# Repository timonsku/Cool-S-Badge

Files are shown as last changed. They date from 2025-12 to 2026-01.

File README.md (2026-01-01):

# Cool-S-Badge

Targets nRF Connect 3.1.1

For Assembly check the docs folder.
TRIPPLE CHECK THE PRO MICRO ORIENTATION before soldering in place

Always update the firmware with the latest version committed to the root of the repo.

OTA Firmware Update
----------------
Download Nordic Device Manager and select the zip file in the DFU/Image tab.
Takes about 30sec after upload before it comes back online.
https://www.nordicsemi.com/Products/Development-tools/nRF-Connect-Device-Manager

Step by step instructions can be found in [OTA.md](docs/OTA/OTA.md)

How to set colors
----------------
Use the "iPixel Color" app in "DIY Drawing" mode to apply LED colors.
Animation support coming soon, bit buggy right now.
Brightness adjustment in Settings menu works but does not persists right now.
Colors persist through reboots if you pressed OK in the editor.

Click the big plus sign to find devices. They are called "LED_XXXXXXXX". With XXXXXXXX being the last four bytes of the MAC address.

Android: https://play.google.com/store/apps/details?id=com.wifiled.ipixels&hl=en

iOS: https://apps.apple.com/us/app/ipixel-color/id1562961996

Turn On/Off
----------------
Press the bottom two buttons for 2 seconds and release to turn off. Press them again to turn back on.

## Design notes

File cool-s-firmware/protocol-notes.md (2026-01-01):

I: cc 18 03 00 00 bd 18 00 |........
I: 00 83 f7 46 f5 02 65 47 |...F..eG

I: 0a 25 03 00 00 fb 24 00 |.%....$.
I: 00 ab ef 5e 96 02 65 47 |...^..eG

scan reponse:
00 72 00 01 05 01
007200010501

	// Fill header
	header[0] = byte(length & 255)
	header[1] = byte((length >> 8) & 255)
	header[2] = dataTypeBytes[0]
	header[3] = dataTypeBytes[1]
	header[4] = byte(option)

func (sc *PacketBuilder) getDataType(dataType int) []byte {
	switch dataType {
	case TYPE_CAMERA, TYPE_DIY_IMAGE_UNREDO:
		return []byte{0, 0}
	case TYPE_VIDEO:
		return []byte{1, 0}
	case TYPE_IMAGE:
		return []byte{2, 0}
	case TYPE_GIF:
		return []byte{3, 0}
	case TYPE_TEXT:
		return []byte{0, 1}
	case TYPE_DIY_IMAGE:
		return []byte{5, 1}
	case TYPE_TEM:
		return []byte{4, 0}
	default:
		return []byte{0, 0}
	}
}

var deviceTypeMap = map[byte]byte{
	129: 2,  // -127 -> Type 2 (32x32)
	128: 0,  // -128 -> Type 0 (64x64)
	130: 4,  // -126 -> Type 4 (32x16)
	131: 3,  // -125 -> Type 3 (64x16)
	132: 1,  // -124 -> Type 1 (96x16)
	133: 5,  // -123 -> Type 5 (64x20)
	134: 6,  // -122 -> Type 6 (128x32)
	135: 7,  // -121 -> Type 7 (144x16)
	136: 8,  // -120 -> Type 8 (192x16)
	137: 9,  // -119 -> Type 9 (48x24)
	138: 10, // -118 -> Type 10 (64x32)
	139: 11, // -117 -> Type 11 (96x32)
	140: 12, // -116 -> Type 12 (128x32)
	141: 13, // -115 -> Type 13 (96x32)
	142: 14, // -114 -> Type 14 (160x32)
	143: 15, // -113 -> Type 15 (192x32)
	144: 16, // -112 -> Type 16 (256x32)
	145: 17, // -111 -> Type 17 (320x32)
	146: 18, // -110 -> Type 18 (384x32)
	147: 19, // -109 -> Type 19 (448x32)
}

packet 2816 App info request: 08 00 01 80 00 02 2c 00

2819 Led Matrix reply: 0b 00 01 80 85 02 2c 00 00 01 00

app: 04 00 05 80

matrix reply: 08 00 05 80 0f 15 01 05

DIY image:
    pixel data:
    I: write_led data:
    I: 0a 00 05 01 00 ff ff ff |........
    I: 07 00                   |..

    header: 0a 00 05 01
    rgb: ff ff ff
    pixel column: 07
    pixel row: 00

request device info message:
	cmd := []byte{
		8,                  // Command header
		0,                  // Reserved
		1,                  // Sub-command
		128,                // 0x80 (corresponds to -128 in signed byte)
		byte(now.Hour()),   // Current hour
		byte(now.Minute()), // Current minute
		byte(now.Second()), // Current second
		0,                  // Language (0 for default)
	}

writing a DIY image with one white pixel and pressing ok (save):
I: Advertising successfully started

I: Connected

I: Notifications enabled
I: Notifications enabled
I: Attribute FA write, handle: 0, conn: 0x200016c8
I: write_led data:
I: 08 00 01 80 01 1e 0a 00 |........
I: Attribute FA write, handle: 0, conn: 0x200016c8
I: write_led data:
I: 04 00 05 80             |....
I: Attribute FA write, handle: 0, conn: 0x200016c8
I: write_led data:
I: 05 00 04 01 01          |.....
I: Attribute FA write, handle: 0, conn: 0x200016c8
I: write_led data:
I: 0a 00 05 01 00 ff ff ff |........
I: 00 00                   |..
I: Attribute FA write, handle: 0, conn: 0x200016c8
I: write_led data:
I: 05 00 04 01 00          |.....
I: Attribute FA write, handle: 0, conn: 0x200016c8
I: write_led data:
I: 07 00 08 80 01 00 02    |.......

long packet inter frame packet?
example 1: 39 a0 45 23 3d 9c 7d 52 00 00 3b
example 2: 39 a0 45 23 3d 9c 7d 52 00 00 3b

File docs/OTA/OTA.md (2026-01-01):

OTA Firmware Update Instructions
=============================

- Install Nordic Device Manager app: https://www.nordicsemi.com/Products/Development-tools/nRF-Connect-Device-Manager

- Download the latest firmware .zip file from the root of this repository. (e.g. cool-s-firmware-v0.4.zip)

- Open the Nordic Device Manager app.

- Click on the "LED_BLE_XXXXXXXX" device in the list. (with XXXXXXXX being the last four bytes of the MAC address)
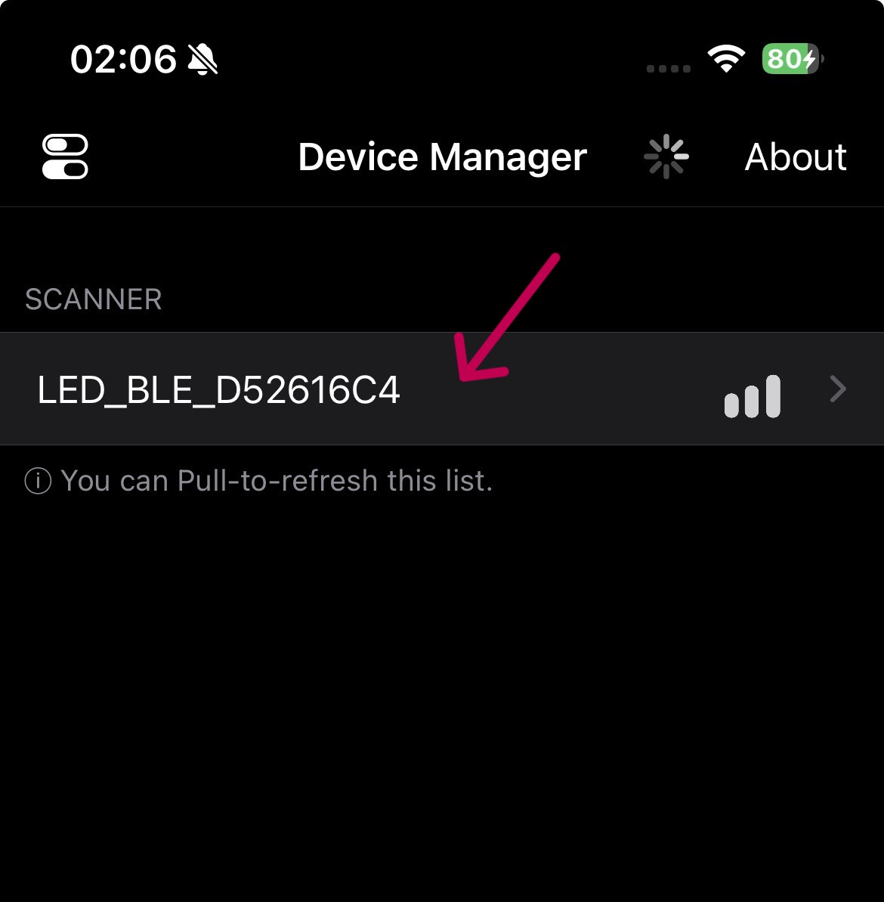
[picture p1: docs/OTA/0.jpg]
picture of selecting device


- If the device does not appear click on the filter icon and untick the "Only nearby devices" option. If its still not showing make sure the device has power.
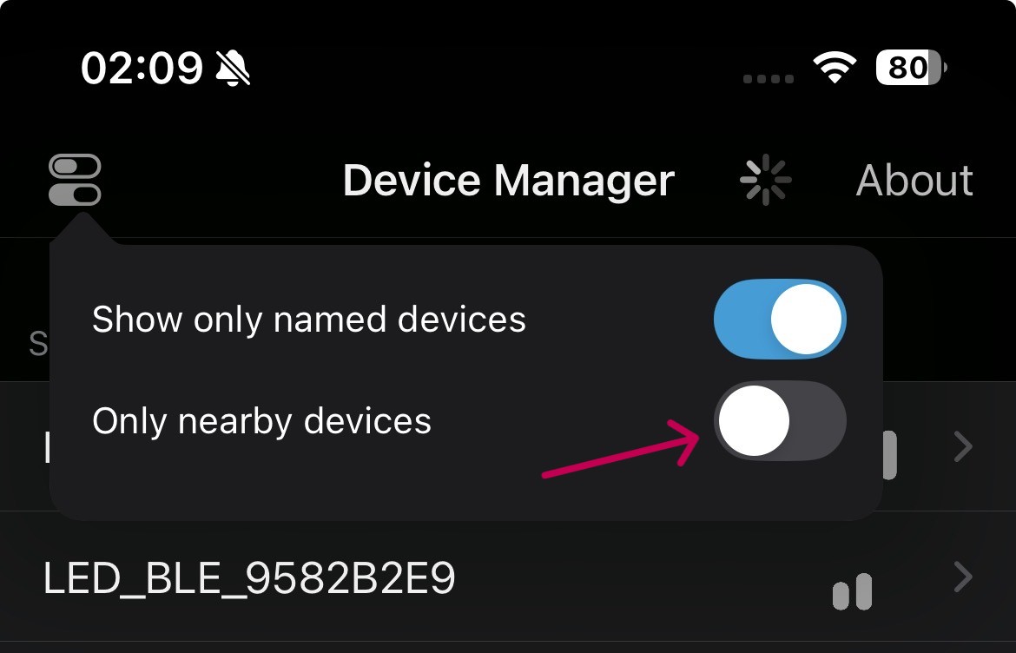
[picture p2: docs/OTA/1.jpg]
picture of filter settings


- Go to the "Image" tab, scroll down and click on the "Select file" button to choose the downloaded .zip firmware file.
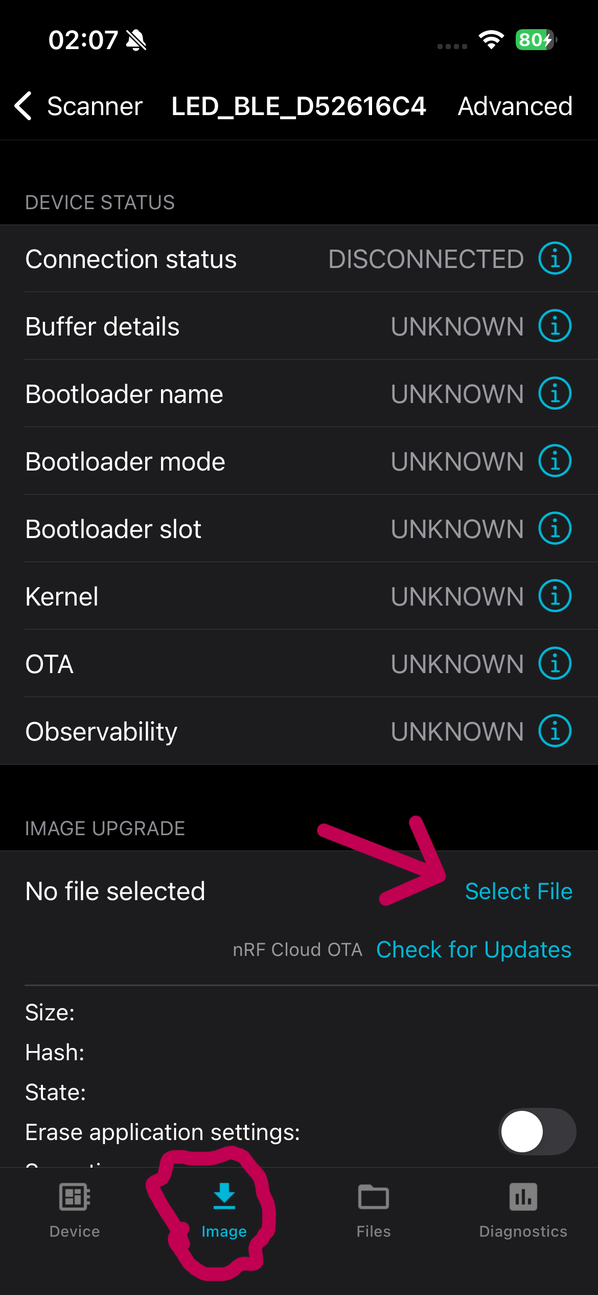
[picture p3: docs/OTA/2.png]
picture of image tab

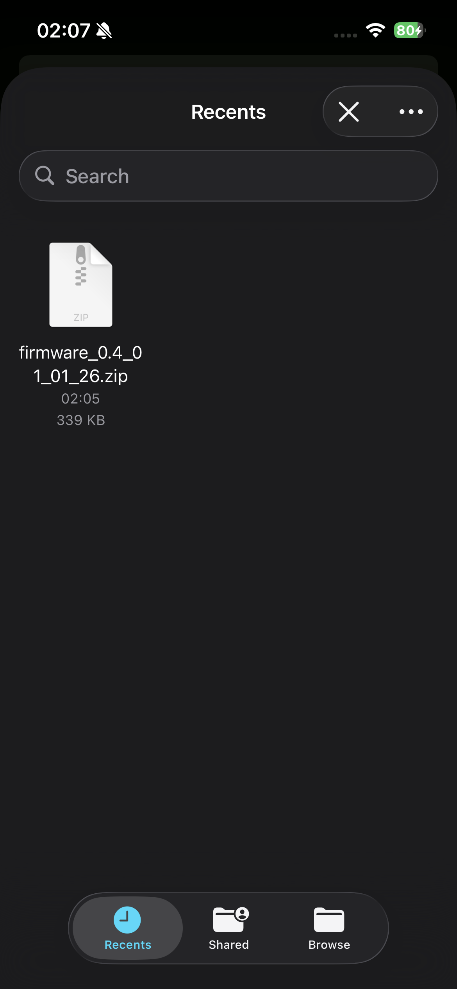
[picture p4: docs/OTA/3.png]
picture of selecting file


- Click on the "Start" button to start the firmware update.
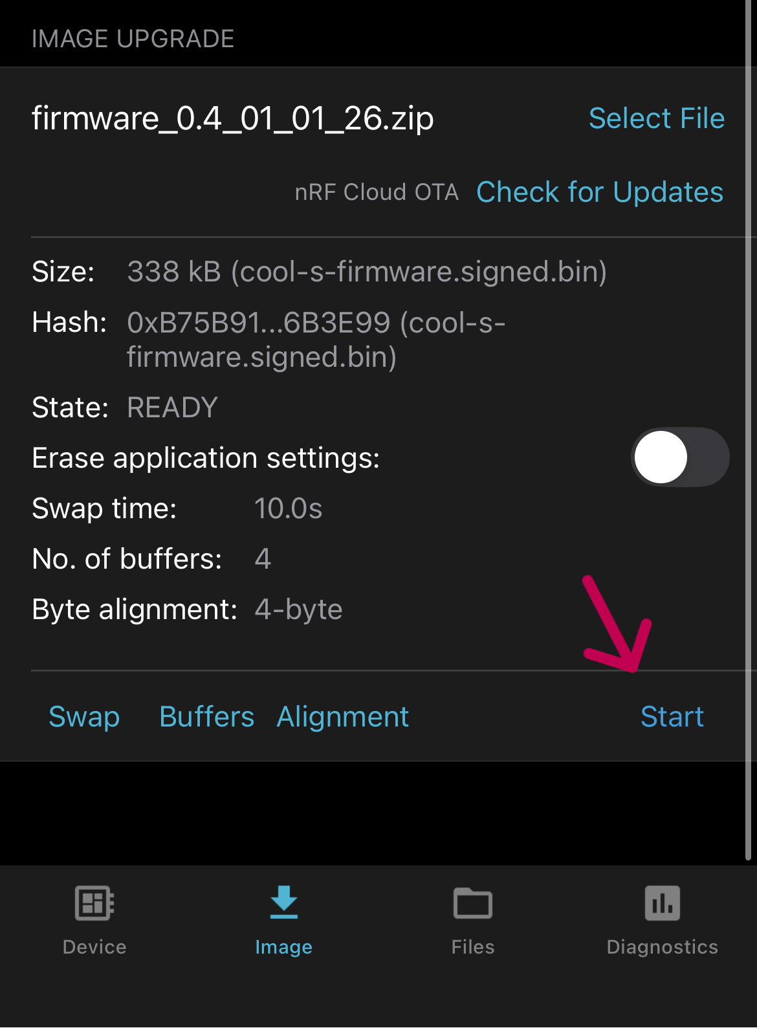
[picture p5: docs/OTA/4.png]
picture of start button


- A popup will ask what type of update to run. Select the recommended "Confirm only" option. If you misclicked don't worry, it will likely still apply the update correctly. If not just start over.
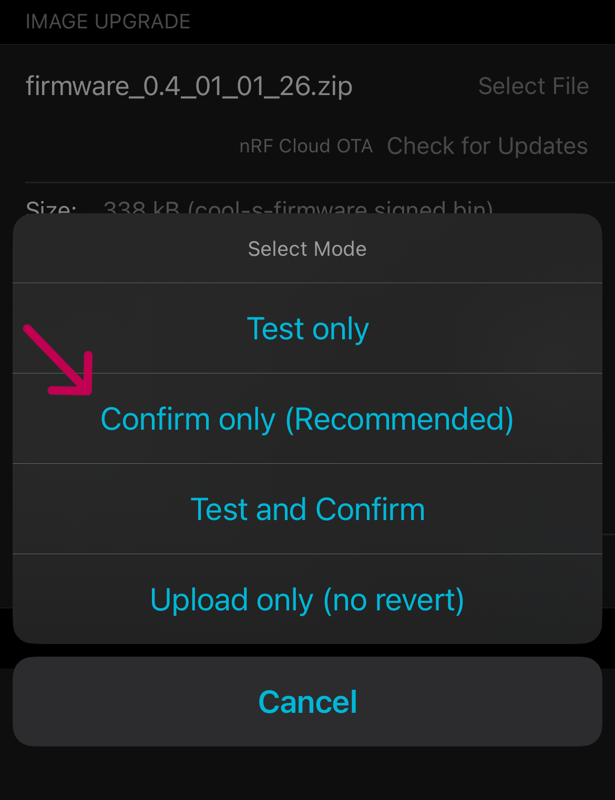
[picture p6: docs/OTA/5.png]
picture of update type selection


- Wait for the update to complete. This may take up to a minute. It should show the "Uploading" message and then start a progress bar after a few seconds. If it immediately says "Upload complete" then you already have the latest firmware installed.
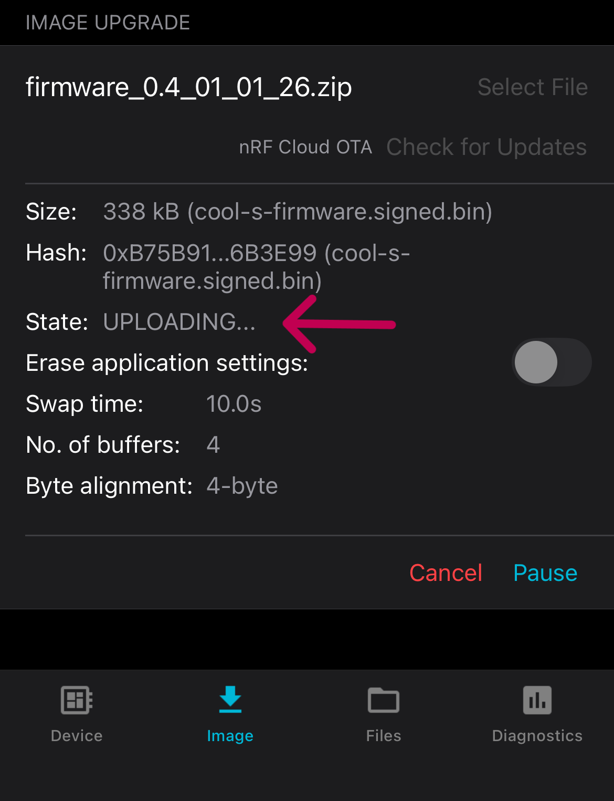
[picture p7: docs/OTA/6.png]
picture of update starting

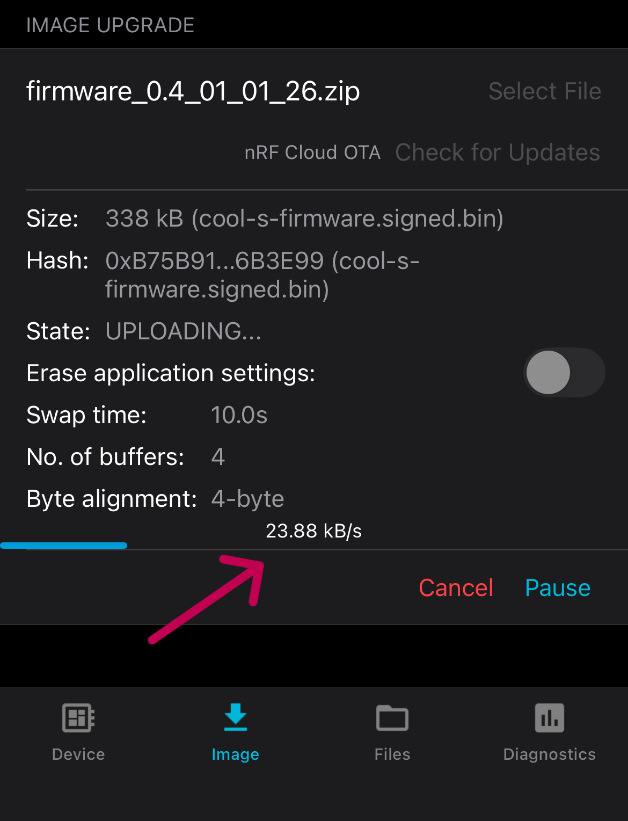
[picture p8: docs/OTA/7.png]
picture of progress bar


- After the upload is complete the device will reboot and should show up again in the device list after about 30 seconds. You can go back to the iPixel app and reconnect to it to verify the new firmware is working. No need to keep the Device Manager app open after the Update Complete message is shown.
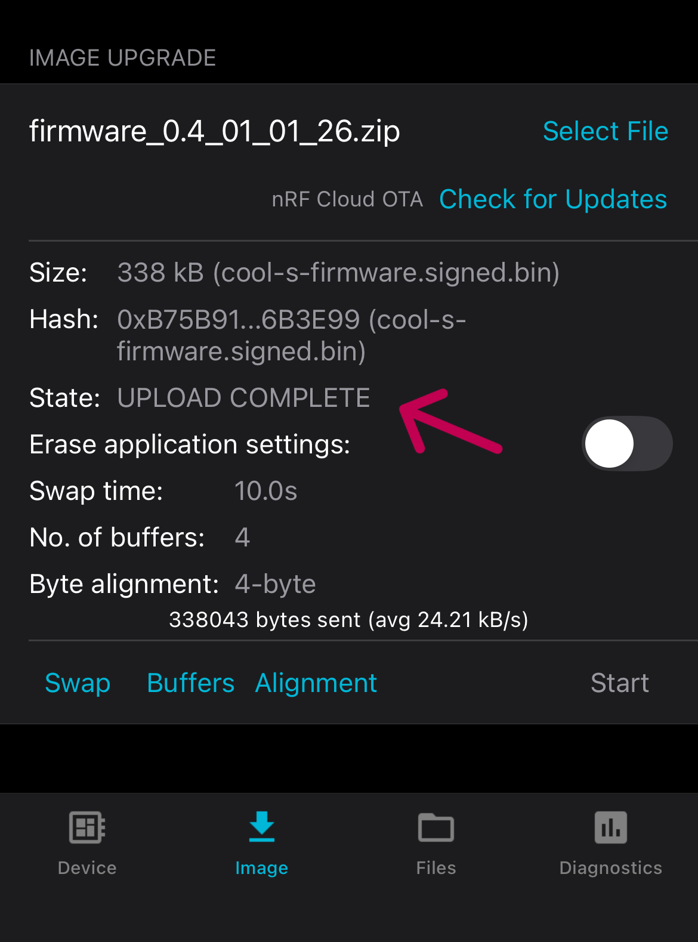
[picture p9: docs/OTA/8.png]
picture of update complete


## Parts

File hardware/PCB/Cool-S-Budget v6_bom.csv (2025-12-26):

Comment | Designator | Footprint | LCSC Part #
10uF | C1 C2 C3 C4 C5 C6 C12 C14 | 603 | C96446
781710002 | J1 | MOLEX_0781710002
DRV2603RUNR | U1 | QFN50P200X200X80-10N
RT9742CGJ5 | IC3 | SOT94P280X100-5N
STEMMA_I2C_QTSKINNY | CONN1 | JST_SH4_SKINNY | C2845363
TS36CA-0.6250GF031SW-SMD_SHOU_TS36CA-0.6 | SW1 SW2 SW3 SW4 | SW-SMD_SHOU_TS36CA-0.6 | C2906288
SK6812MINI-HS | U3 U4 U5 U6 U7 U8 U9 U10 U11 U12 U13 U14 U15 U16 U17 U18 U19 U20 U21 U22 U23 U24 U25 U26 U27 U28 U29 U30 U31 U32 | SK6812MINI-HS | C2922787

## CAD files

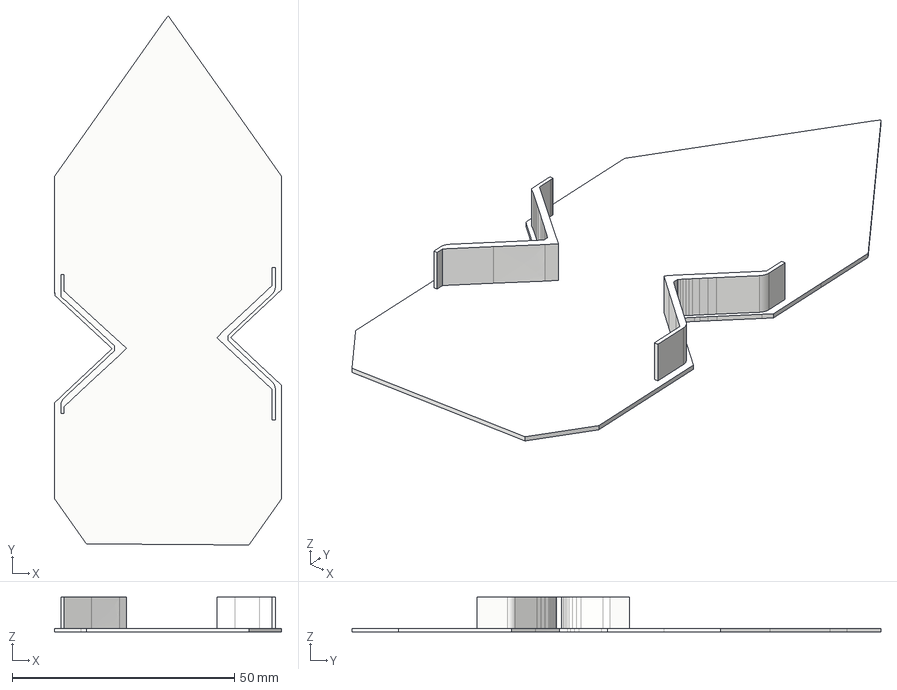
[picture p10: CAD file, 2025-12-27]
hardware/3D CAD/Back-Cover-Cool-S.step
51.1 x 119.0 x 7.80 mm

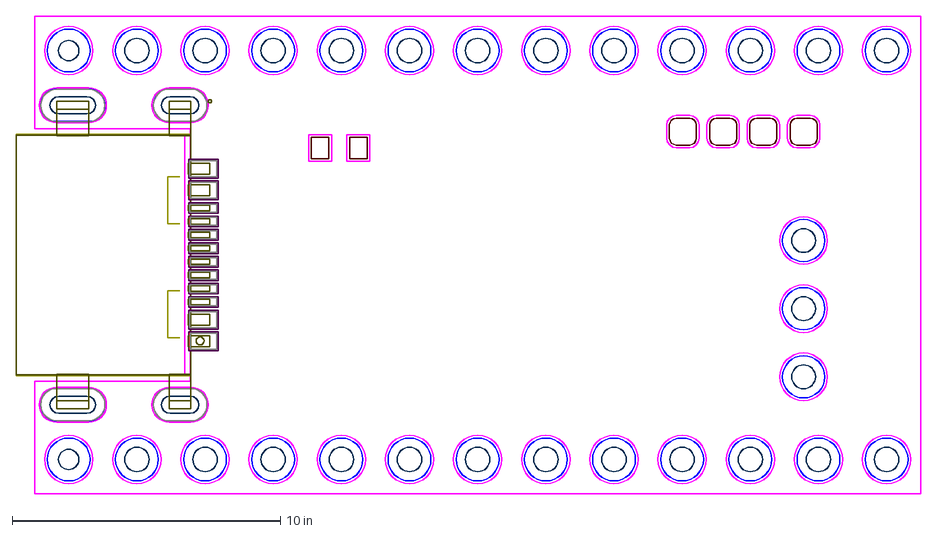
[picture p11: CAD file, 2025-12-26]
hardware/3D CAD/ProMicro_NRF52840 V1.2-PCB FootPrint.DXF
33.7 x 17.8 in

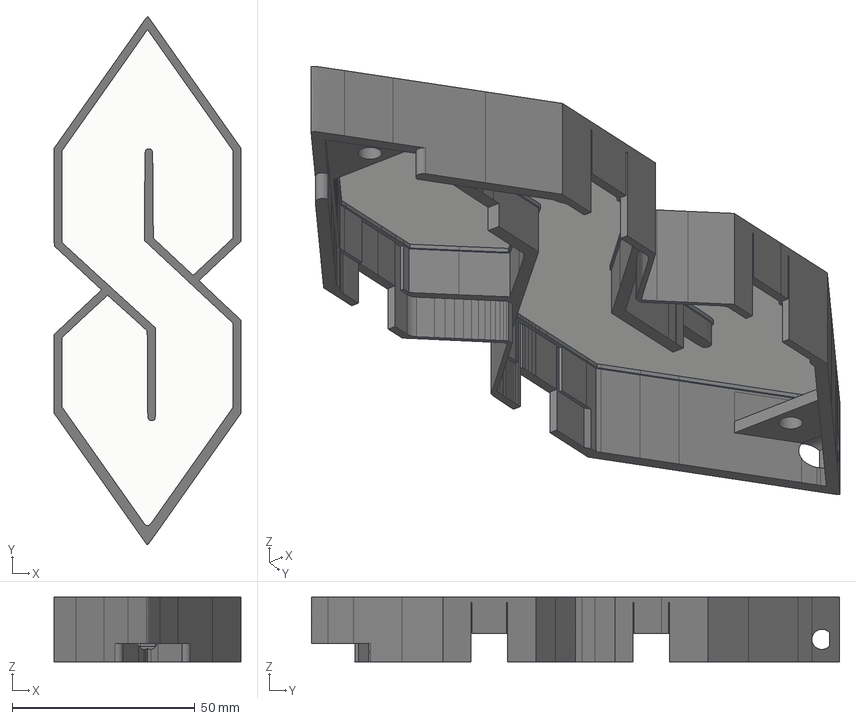
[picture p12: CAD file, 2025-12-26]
hardware/3D CAD/Cool-S-Case.step
51.1 x 144.5 x 17.7 mm

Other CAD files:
hardware/3D CAD/Cool-S-Case.3mf

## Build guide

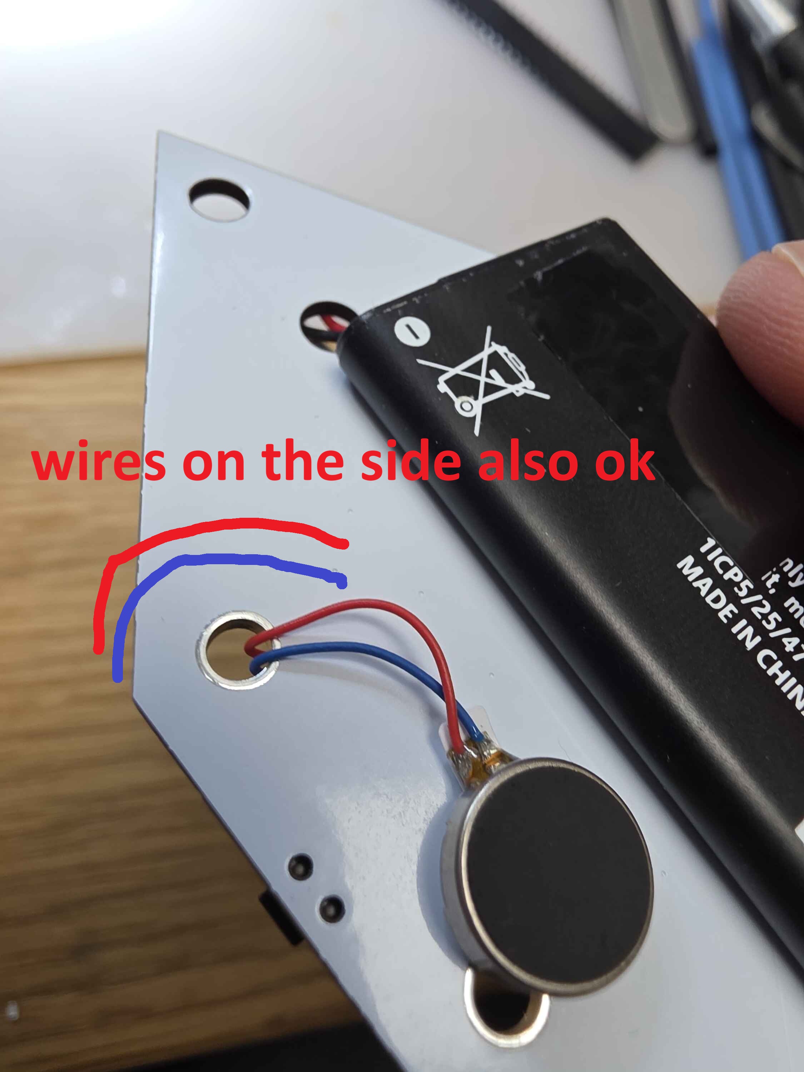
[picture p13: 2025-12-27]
docs/assembly/6.jpg

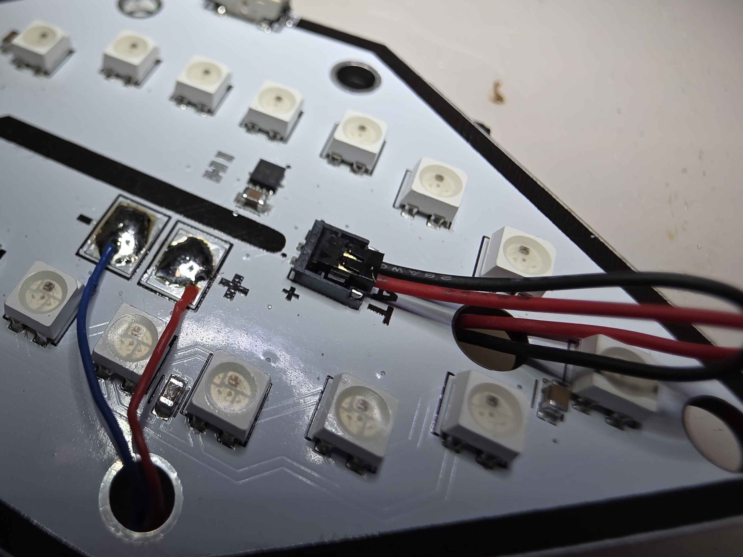
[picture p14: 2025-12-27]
docs/assembly/5.jpg

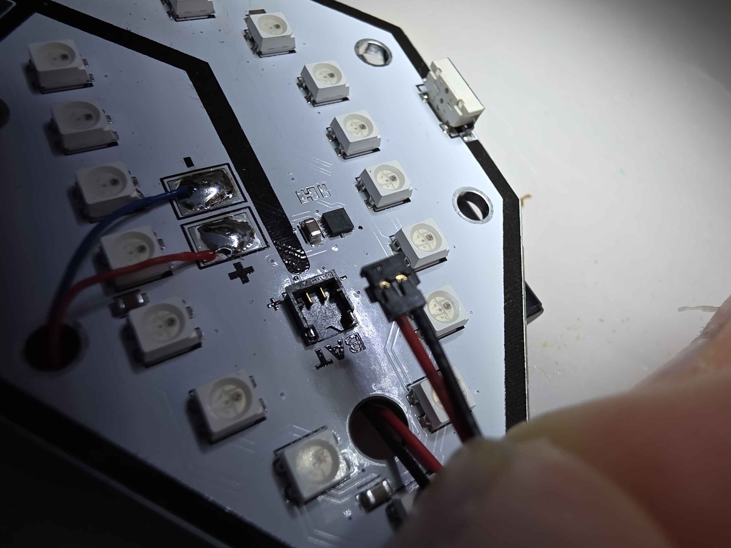
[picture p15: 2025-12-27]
docs/assembly/4.jpg

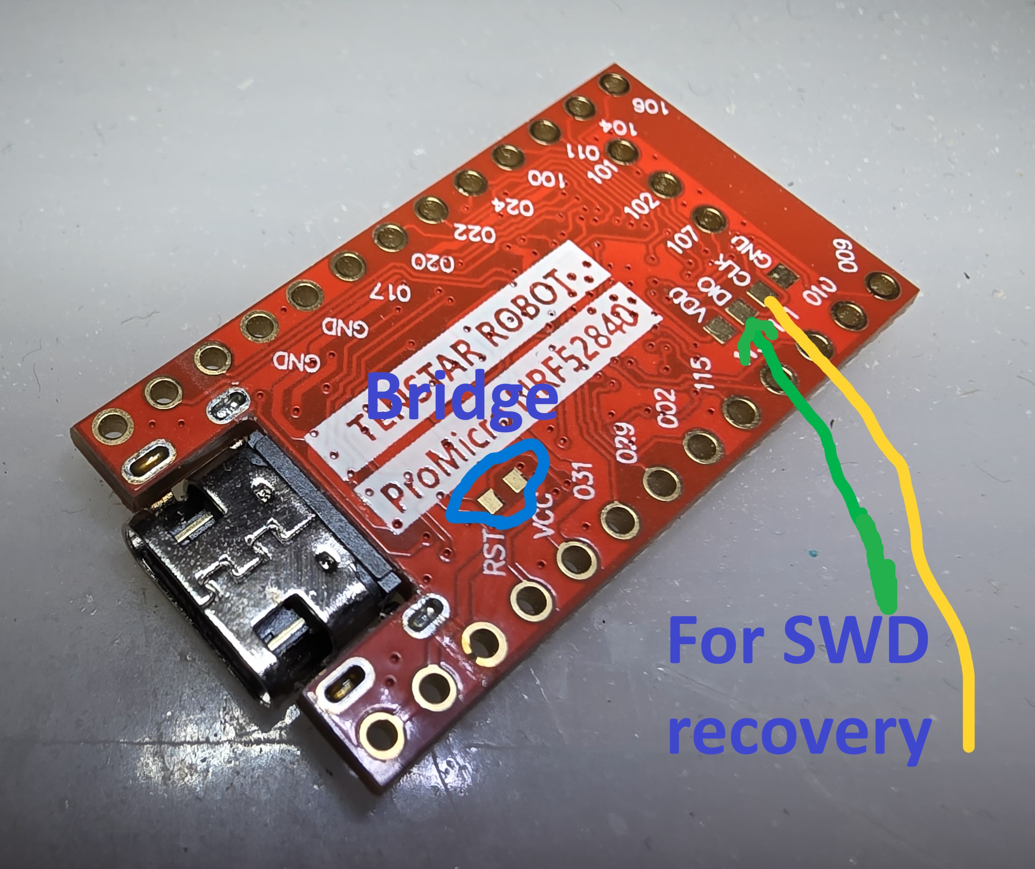
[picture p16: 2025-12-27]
docs/assembly/0-board-prep-IMPORTANT-DO-THIS-FIRST.jpg

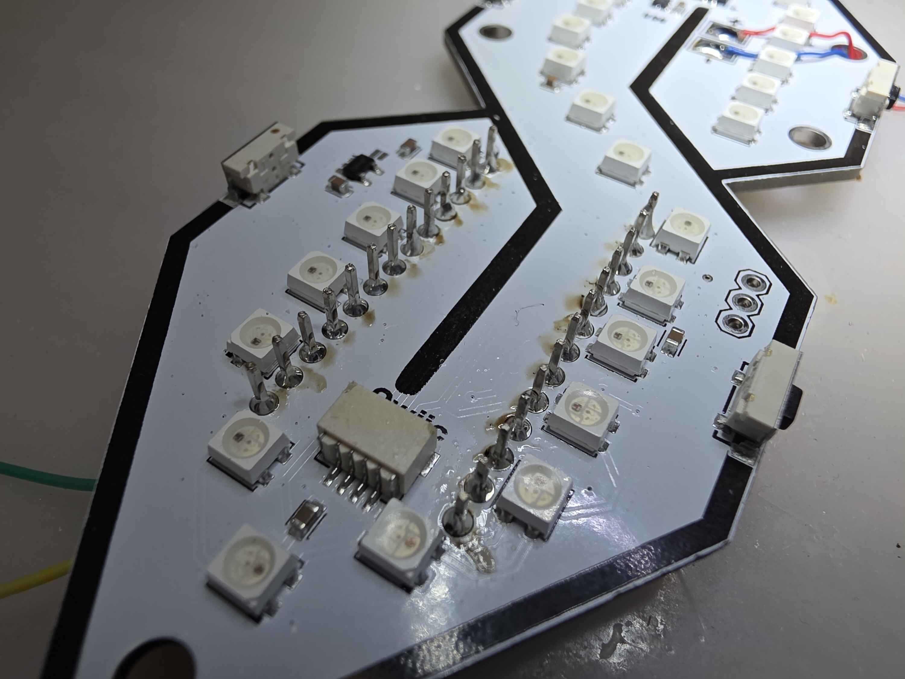
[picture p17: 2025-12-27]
docs/assembly/2.jpg

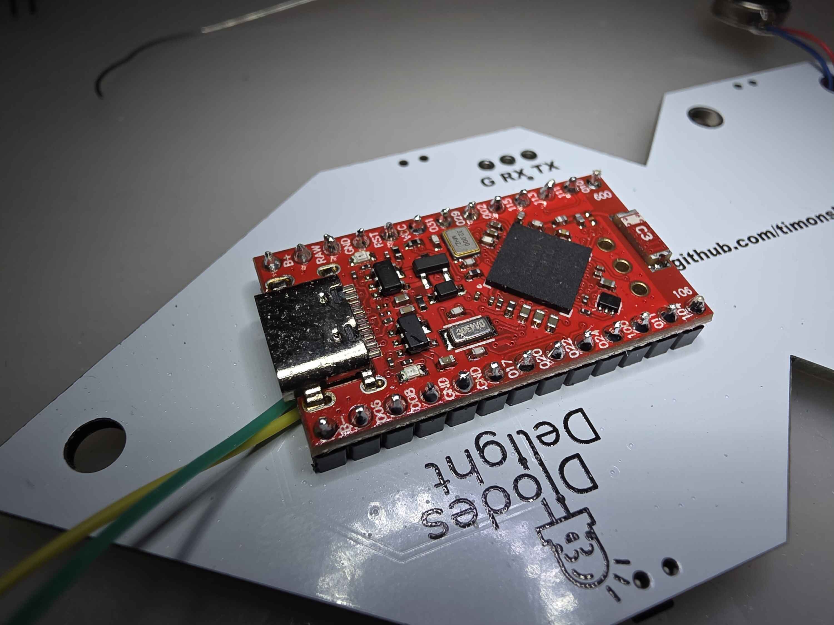
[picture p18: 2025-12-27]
docs/assembly/1.jpg

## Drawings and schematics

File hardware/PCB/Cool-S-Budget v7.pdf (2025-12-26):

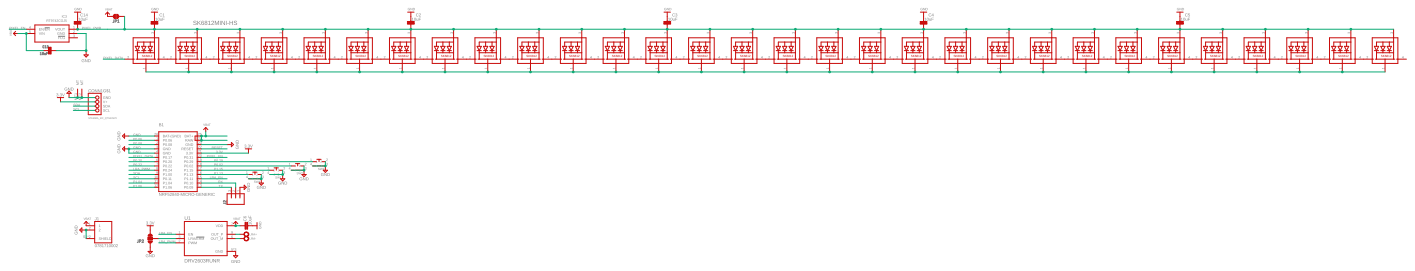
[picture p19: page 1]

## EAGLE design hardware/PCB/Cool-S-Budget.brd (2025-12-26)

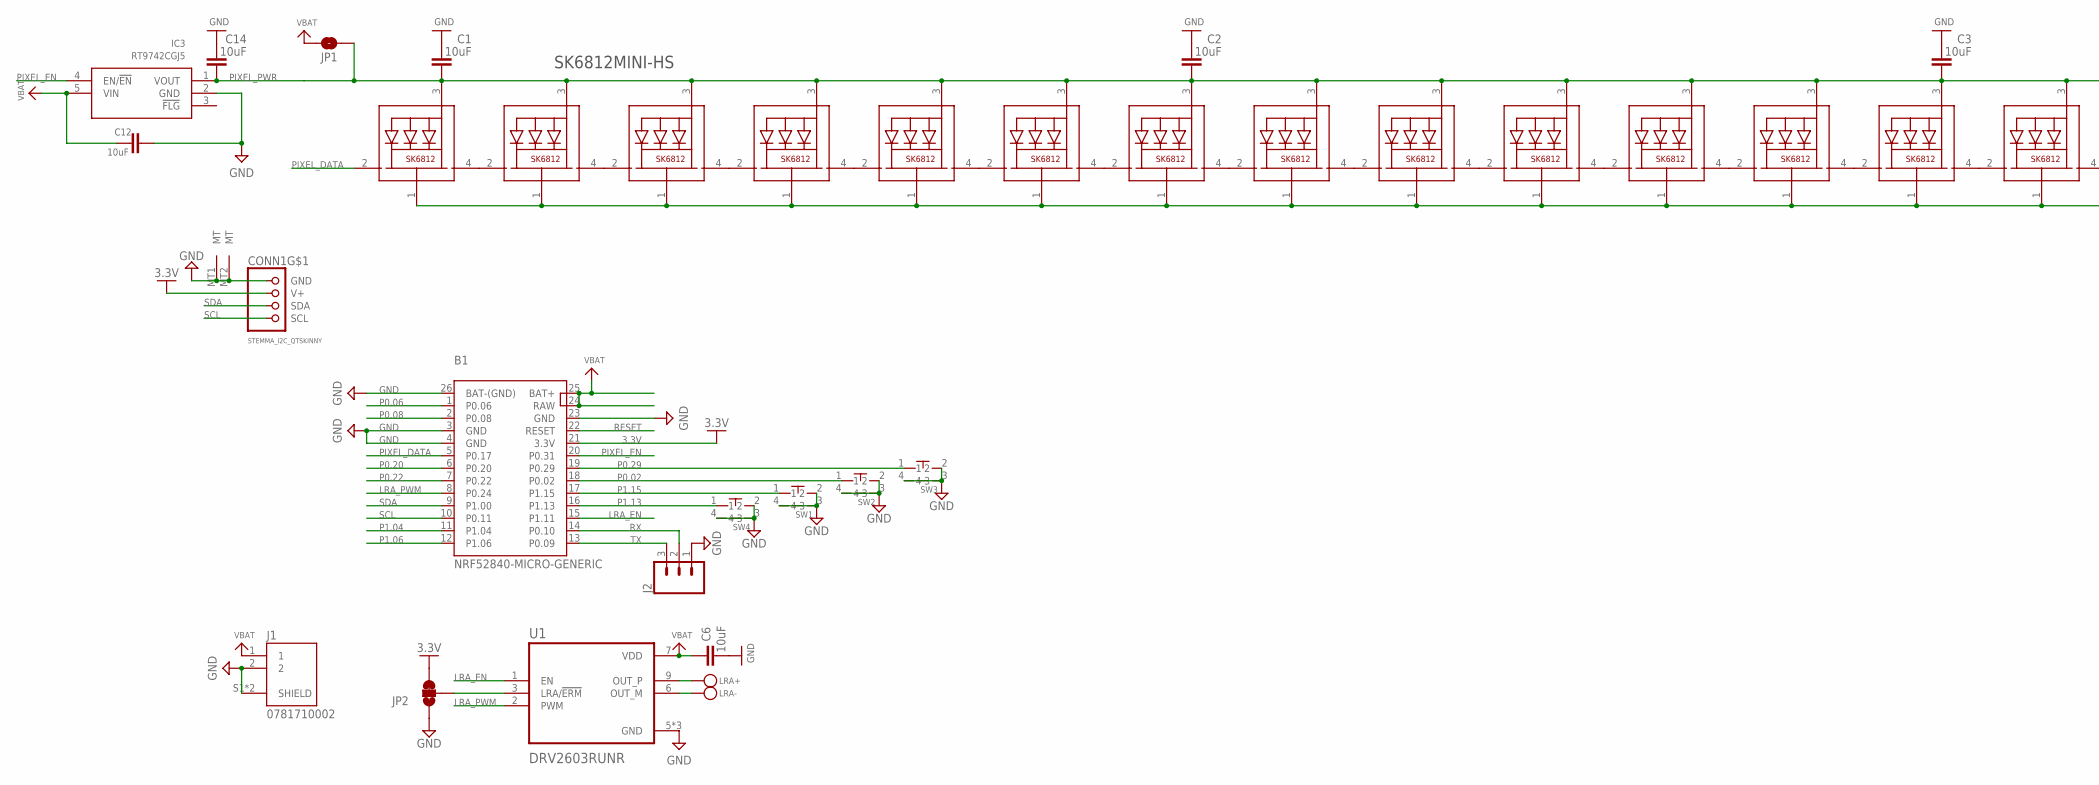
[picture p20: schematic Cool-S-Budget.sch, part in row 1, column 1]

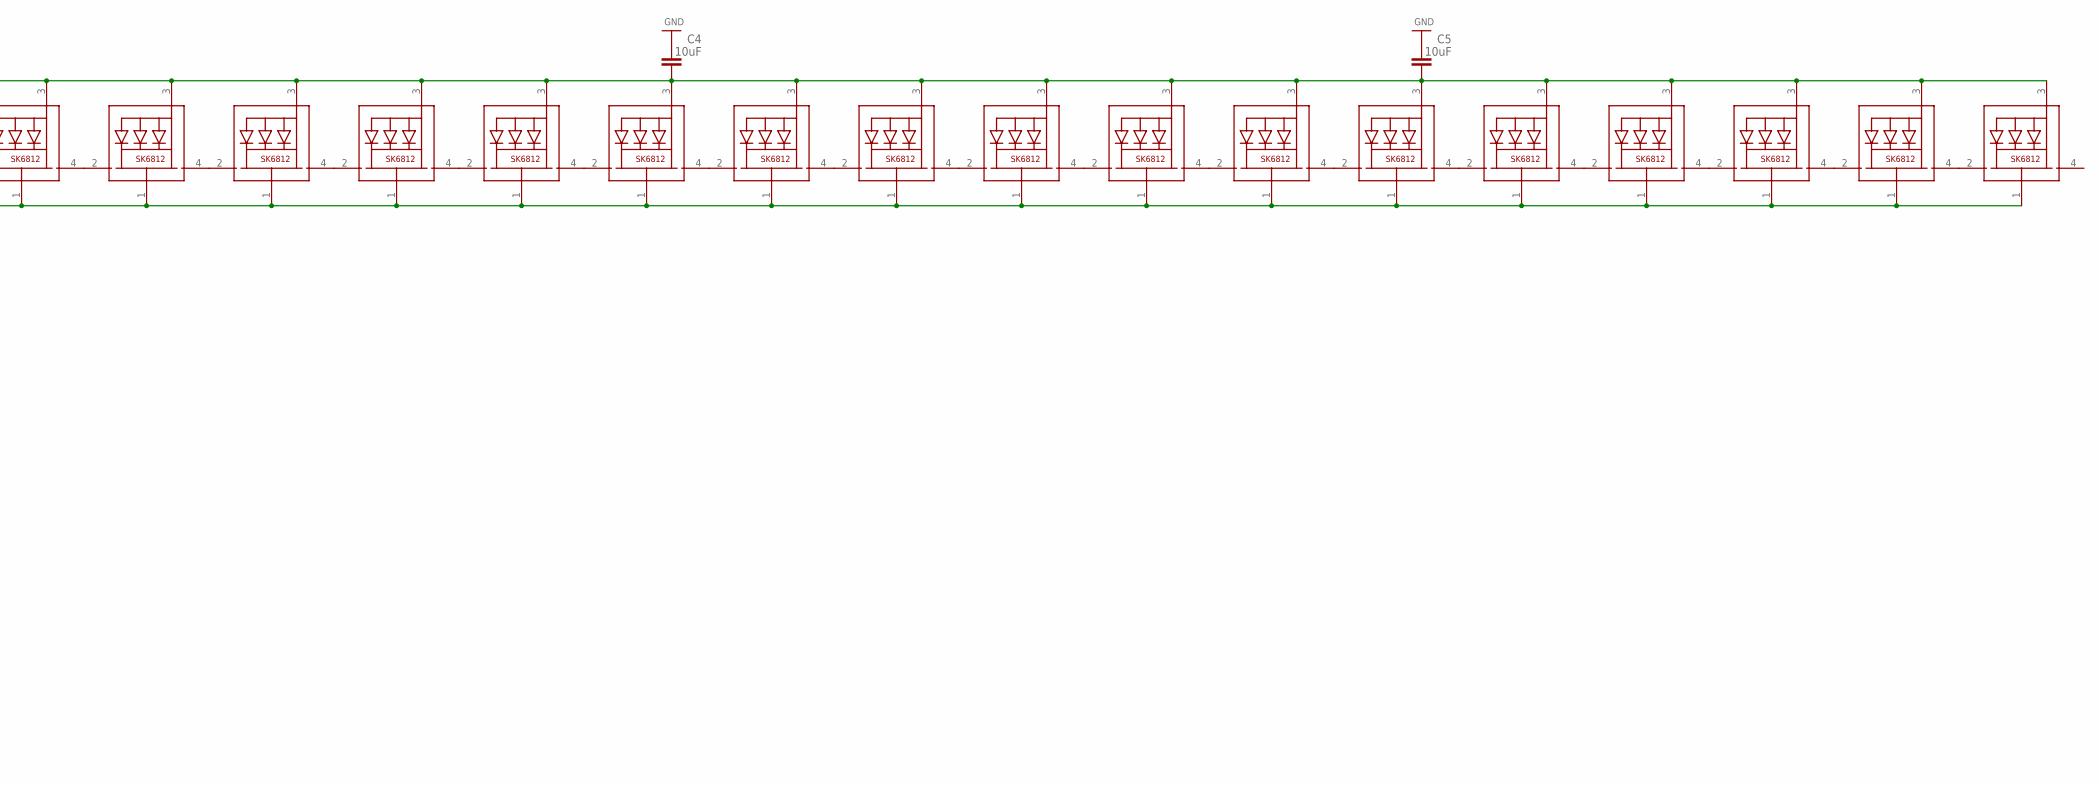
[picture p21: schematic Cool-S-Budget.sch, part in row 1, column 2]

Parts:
B1: NRF52840-MICRO-GENERIC
C1, C2, C3, C4, C5, C6, C12, C14: 10uF; CAPC1608X85
CONN1: STEMMA_I2C_QTSKINNY; JST_SH4_SKINNY
IC3: RT9742CGJ5; SOT94P280X100-5N
J1: 0781710002; MOLEX_0781710002
J2: 455-1750-1-ND; 1X03
JP1: JUMPER-SMT_2_NO_NO-SILK; SMT-JUMPER_2_NO_NO-SILK
JP2: JUMPER-SMT_3_1-NC_TRACE_NO-SILK; SMT-JUMPER_3_1-NC_TRACE_NO-SILK
LRA+: TESTPOINT; TESTPOINT_SMT
LRA-: TESTPOINT; TESTPOINT_SMT
SW1, SW2, SW3, SW4: TS36CA-0.6250GF031SW-SMD_SHOU_TS36CA-0.6; SW-SMD_SHOU_TS36CA-0.6; LCSC C2906288
U1: DRV2603RUNR; QFN50P200X200X80-10N
U3, U4, U5, U6, U7, U8, U9, U10, U11, U12, U13, U14, U15, U16, U17, U18, U19, U20, U21, U22, U23, U24, U25, U26, U27, U28, U29, U30, U31, U32: SK6812MINI; LED3535

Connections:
3.3V: B1.21 (3.3V), CONN1.2 (V+), JP2.3
GND: B1.3 (GND), B1.4 (GND), B1.23 (GND), B1.26 (BAT-(GND)), C1.1, C2.1, C3.1, C4.1, C5.1, C6.1, C12.2, C14.1, CONN1.1 (GND), CONN1.MT1 (MT), CONN1.MT2 (MT), IC3.2 (GND), J1.2, J1.S1 (SHIELD), J1.S2 (SHIELD), J2.1, JP2.1, SW1.2, SW1.3, SW1.4, SW2.2, SW2.3, SW2.4, SW3.2, SW3.3, SW3.4, SW4.2, SW4.3, SW4.4, U1.5 (GND), U1.8 (GND), U1.10 (GND), U3.1 (GND), U4.1 (GND), U5.1 (GND), U6.1 (GND), U7.1 (GND), U8.1 (GND), U9.1 (GND), U10.1 (GND), U11.1 (GND), U12.1 (GND), U13.1 (GND), U14.1 (GND), U15.1 (GND), U16.1 (GND), U17.1 (GND), U18.1 (GND), U19.1 (GND), U20.1 (GND), U21.1 (GND), U22.1 (GND), U23.1 (GND), U24.1 (GND), U25.1 (GND), U26.1 (GND), U27.1 (GND), U28.1 (GND), U29.1 (GND), U30.1 (GND), U31.1 (GND), U32.1 (GND)
LRA+: LRA+.P$1, U1.9 (OUT_P)
LRA-: LRA-.P$1, U1.6 (OUT_M)
LRA_EN: B1.15 (P1.11), U1.1 (EN)
LRA_PWM: B1.8 (P0.24), U1.2 (PWM)
unnamed: U3.2 (DI), U4.4 (DO)
unnamed: U4.2 (DI), U5.4 (DO)
unnamed: U5.2 (DI), U6.4 (DO)
unnamed: U6.2 (DI), U7.4 (DO)
unnamed: U8.2 (DI), U9.4 (DO)
unnamed: U9.2 (DI), U10.4 (DO)
unnamed: U11.2 (DI), U12.4 (DO)
unnamed: U7.2 (DI), U8.4 (DO)
unnamed: U12.2 (DI), U13.4 (DO)
unnamed: U13.2 (DI), U14.4 (DO)
unnamed: U14.2 (DI), U15.4 (DO)
unnamed: U16.2 (DI), U17.4 (DO)
unnamed: U17.2 (DI), U18.4 (DO)
unnamed: U15.2 (DI), U16.4 (DO)
unnamed: U10.2 (DI), U11.4 (DO)
unnamed: U19.2 (DI), U20.4 (DO)
unnamed: U20.2 (DI), U21.4 (DO)
unnamed: U21.2 (DI), U22.4 (DO)
unnamed: U22.2 (DI), U23.4 (DO)
unnamed: U24.2 (DI), U25.4 (DO)
unnamed: U25.2 (DI), U26.4 (DO)
unnamed: U23.2 (DI), U24.4 (DO)
unnamed: U27.2 (DI), U28.4 (DO)
unnamed: U28.2 (DI), U29.4 (DO)
unnamed: U29.2 (DI), U30.4 (DO)
unnamed: U30.2 (DI), U31.4 (DO)
unnamed: JP2.2, U1.3 (LRA/!ERM)
unnamed: U31.2 (DI), U32.4 (DO)
unnamed: U26.2 (DI), U27.4 (DO)
unnamed: U18.2 (DI), U19.4 (DO)
P0.02: B1.18 (P0.02), SW2.1
P0.06: B1.1 (P0.06)
P0.08: B1.2 (P0.08)
P0.20: B1.6 (P0.20)
P0.22: B1.7 (P0.22)
P0.29: B1.19 (P0.29), SW3.1
P1.04: B1.11 (P1.04)
P1.06: B1.12 (P1.06)
P1.13: B1.16 (P1.13), SW4.1
P1.15: B1.17 (P1.15), SW1.1
PIXEL_DATA: B1.5 (P0.17), U32.2 (DI)
PIXEL_EN: B1.20 (P0.31), IC3.4 (EN/!EN)
PIXEL_PWR: C1.2, C2.2, C3.2, C4.2, C5.2, C14.2, IC3.1 (VOUT), JP1.1, U3.3 (VDD), U4.3 (VDD), U5.3 (VDD), U6.3 (VDD), U7.3 (VDD), U8.3 (VDD), U9.3 (VDD), U10.3 (VDD), U11.3 (VDD), U12.3 (VDD), U13.3 (VDD), U14.3 (VDD), U15.3 (VDD), U16.3 (VDD), U17.3 (VDD), U18.3 (VDD), U19.3 (VDD), U20.3 (VDD), U21.3 (VDD), U22.3 (VDD), U23.3 (VDD), U24.3 (VDD), U25.3 (VDD), U26.3 (VDD), U27.3 (VDD), U28.3 (VDD), U29.3 (VDD), U30.3 (VDD), U31.3 (VDD), U32.3 (VDD)
RESET: B1.22 (RESET)
RX: B1.14 (P0.10), J2.2
SCL: B1.10 (P0.11), CONN1.4 (SCL)
SDA: B1.9 (P1.00), CONN1.3 (SDA)
TX: B1.13 (P0.09), J2.3
VBAT: B1.24 (RAW), B1.25 (BAT+), C6.2, C12.1, IC3.5 (VIN), J1.1, JP1.2, U1.7 (VDD)

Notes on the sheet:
SK6812MINI-HS

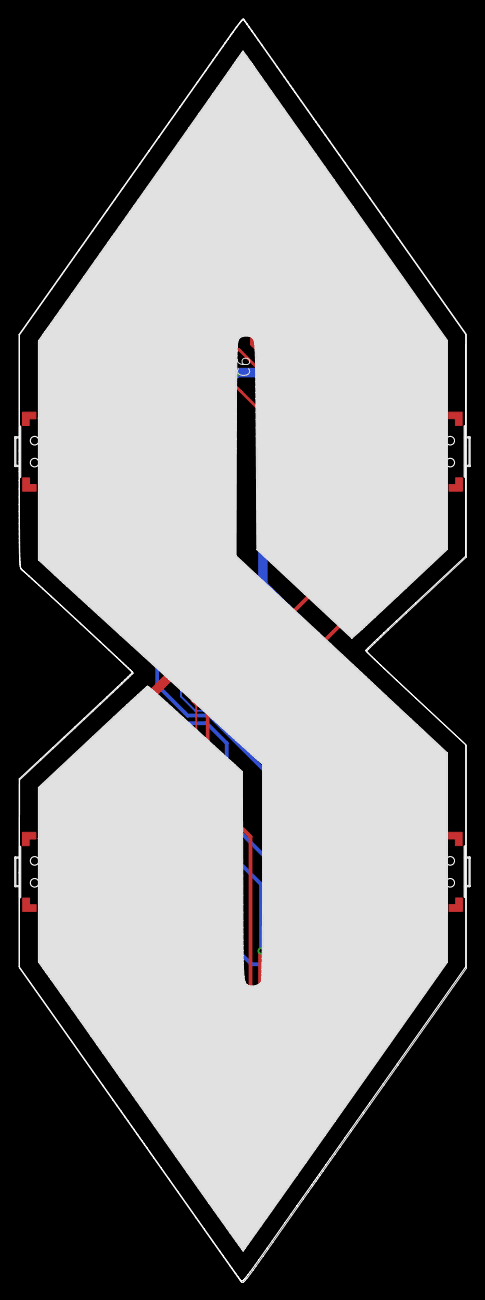
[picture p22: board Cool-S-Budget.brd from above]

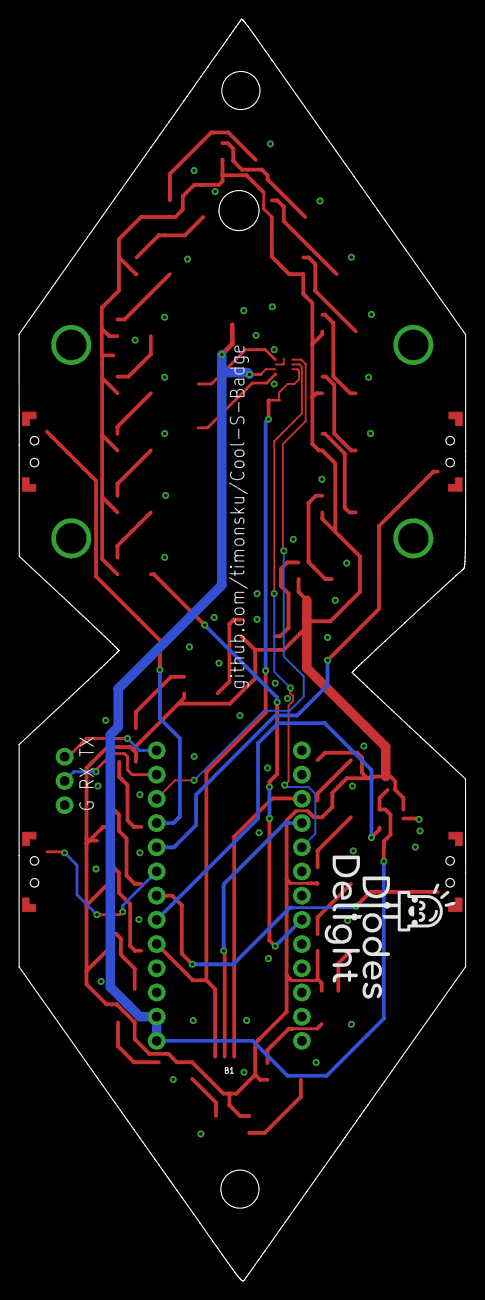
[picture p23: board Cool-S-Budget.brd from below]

Board: 2 copper layers, 46.9 x 132.4 mm, 53 parts (2 on the bottom side), 48 nets.

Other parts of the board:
U$4: DIODES-DELIGHT-LOGO-15X15

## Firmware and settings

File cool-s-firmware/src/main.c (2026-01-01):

/*
 * Copyright (c) 2018 Nordic Semiconductor ASA
 *
 * SPDX-License-Identifier: LicenseRef-Nordic-5-Clause
 */

#include <zephyr/types.h>
#include <stddef.h>
#include <string.h>
#include <errno.h>
#include <zephyr/sys/printk.h>
#include <zephyr/sys/byteorder.h>
#include <zephyr/kernel.h>
#include <zephyr/drivers/gpio.h>
#include <soc.h>
#include <stdlib.h>
#include <math.h>
#include <zephyr/usb/usb_device.h>
#include <zephyr/drivers/regulator.h>
#include <zephyr/retention/bootmode.h>
#include <zephyr/sys/reboot.h>
#include <zephyr/input/input.h>
#include <zephyr/sys/poweroff.h>

#include <zephyr/bluetooth/bluetooth.h>
#include <zephyr/bluetooth/hci.h>
#include <zephyr/bluetooth/conn.h>
#include <zephyr/bluetooth/uuid.h>
#include <zephyr/bluetooth/gatt.h>

// #include <bluetooth/services/lbs.h>

#include <zephyr/settings/settings.h>
#include <zephyr/logging/log.h>
#include <dk_buttons_and_leds.h>

#include <zephyr/drivers/led_strip.h>
#include <zephyr/device.h>
#include <zephyr/drivers/spi.h>
#include <zephyr/sys/util.h>

#include <zephyr/device.h>
#include <zephyr/fs/fs.h>
#include <zephyr/fs/littlefs.h>

#ifdef CONFIG_MCUMGR_GRP_STAT
#include <zephyr/mgmt/mcumgr/grp/stat_mgmt/stat_mgmt.h>
#endif

#include <zephyr/mgmt/mcumgr/transport/smp_bt.h>
#include <zephyr/dfu/mcuboot.h>

#define STORAGE_PARTITION_LABEL	storage_partition
#define STORAGE_PARTITION_ID	FIXED_PARTITION_ID(STORAGE_PARTITION_LABEL)

#define FW_VERSION_MAJOR 0
#define FW_VERSION_MINOR 5

/* Define an example stats group; approximates seconds since boot. */
STATS_SECT_START(smp_svr_stats)
STATS_SECT_ENTRY(ticks)
STATS_SECT_ENTRY(version_major)
STATS_SECT_ENTRY(version_minor)
STATS_SECT_END;

/* Assign a name to the `ticks` stat. */
STATS_NAME_START(smp_svr_stats)
STATS_NAME(smp_svr_stats, ticks)
STATS_NAME(smp_svr_stats, version_major)
STATS_NAME(smp_svr_stats, version_minor)
STATS_NAME_END(smp_svr_stats);

/* Define an instance of the stats group. */
STATS_SECT_DECL(smp_svr_stats) smp_svr_stats;


FS_LITTLEFS_DECLARE_DEFAULT_CONFIG(cstorage);
static struct fs_mount_t littlefs_mnt = {
	.type = FS_LITTLEFS,
	.fs_data = &cstorage,
	.storage_dev = (void *)STORAGE_PARTITION_ID,
	.mnt_point = "/lfs1"
};


// #define SPNG_USE_MINIZ
// #include "spng.h"
static struct k_sem sync;

static uint8_t device_name[] = {'L', 'E', 'D', '_', 'B', 'L','E','_','C', 'O', 'O', 'L','0','0','0','0'};

const struct device *led_en = DEVICE_DT_GET(DT_NODELABEL(led_pwr));
#define STRIP_NODE		DT_ALIAS(led_strip)
#if DT_NODE_HAS_PROP(DT_ALIAS(led_strip), chain_length)
#define STRIP_NUM_PIXELS	DT_PROP(DT_ALIAS(led_strip), chain_length)
#else
#error Unable to determine length of LED strip
#endif
static struct led_rgb pixels_raw[STRIP_NUM_PIXELS];
static struct led_rgb pixels[STRIP_NUM_PIXELS];
static const struct device *const strip = DEVICE_DT_GET(STRIP_NODE);

#define GIF_IMPLEMENTATION
#include "gif.h"
#define SCRATCH_BUFFER_SIZE GIF_SCRATCH_BUFFER_REQUIRED_SIZE
uint8_t scratch_buffer[SCRATCH_BUFFER_SIZE]; 

struct pixel_animation_frame {
	uint16_t duration_ms;
	struct led_rgb pixels[STRIP_NUM_PIXELS];
};

struct pixel_animation {
	uint16_t num_frames;
	struct pixel_animation_frame *frames;
};

struct pixel_animation current_animation;
bool playAnimation = false;

LOG_MODULE_REGISTER(app);

// #define DEVICE_NAME             CONFIG_BT_DEVICE_NAME
// #define DEVICE_NAME_LEN         (sizeof(DEVICE_NAME) - 1)


#define RUN_STATUS_LED          DK_LED1
#define CON_STATUS_LED          DK_LED2
#define RUN_LED_BLINK_INTERVAL  1000

#define USER_LED                DK_LED3

#define USER_BUTTON             DK_BTN1_MSK

static bool button0 = false;
static bool button1 = false;
static bool button2 = false;
static bool button3 = false;
static bool                   notify_enabled;
static struct k_work adv_work;
	
#define BT_UUID_IPIXEL_SRV_VAL BT_UUID_16_ENCODE(0x00fa)
	// BT_UUID_128_ENCODE(0x000000fa, 0x0000, 0x1000, 0x8000, 0x00805f9b34fb)

#define BT_UUID_IPIXEL_WRITE_VAL BT_UUID_16_ENCODE(0xfa02)
	// BT_UUID_128_ENCODE(0x0000fa02, 0x0000, 0x1000, 0x8000, 0x00805f9b34fb)

#define BT_UUID_IPIXEL_NOTIFY_VAL BT_UUID_16_ENCODE(0xfa03)
	// BT_UUID_128_ENCODE(0x0000fa03, 0x0000, 0x1000, 0x8000, 0x00805f9b34fb)

// #define BT_UUID_IPIXEL_SRV_AE_VAL BT_UUID_128_ENCODE(0x0000ae00, 0x0000, 0x1000, 0x8000, 0x00805f9b34fb)

// #define BT_UUID_IPIXEL_WRITE_AE_VAL BT_UUID_128_ENCODE(0x0000ae01, 0x0000, 0x1000, 0x8000, 0x00805f9b34fb)

// #define BT_UUID_IPIXEL_NOTIFY_AE_VAL BT_UUID_128_ENCODE(0x0000ae02, 0x0000, 0x1000, 0x8000, 0x00805f9b34fb)


// #define BT_UUID_IPIXEL_SRV    BT_UUID_DECLARE_128(BT_UUID_IPIXEL_SRV_VAL)
// #define BT_UUID_IPIXEL_WRITE    BT_UUID_DECLARE_128(BT_UUID_IPIXEL_WRITE_VAL)
// #define BT_UUID_IPIXEL_NOTIFY    BT_UUID_DECLARE_128(BT_UUID_IPIXEL_NOTIFY_VAL)

#define BT_UUID_IPIXEL_SRV    BT_UUID_DECLARE_16(0x00fa)
#define BT_UUID_IPIXEL_WRITE    BT_UUID_DECLARE_16(0xfa02)
#define BT_UUID_IPIXEL_NOTIFY    BT_UUID_DECLARE_16(0xfa03)

// #define BT_UUID_IPIXEL_SRV_AE    BT_UUID_DECLARE_128(BT_UUID_IPIXEL_SRV_AE_VAL)
// #define BT_UUID_IPIXEL_WRITE_AE    BT_UUID_DECLARE_128(BT_UUID_IPIXEL_WRITE_AE_VAL)
// #define BT_UUID_IPIXEL_NOTIFY_AE    BT_UUID_DECLARE_128(BT_UUID_IPIXEL_NOTIFY_AE_VAL)



static const struct bt_data ad[] = {
	BT_DATA_BYTES(BT_DATA_FLAGS, (BT_LE_AD_GENERAL | BT_LE_AD_NO_BREDR)),
	BT_DATA(BT_DATA_NAME_COMPLETE, device_name, sizeof(device_name)),
	
};

static const uint8_t led_scan_resp[] = {0x00, 0x72, 0x00, 0x01, 0x05, 0x01};

static const struct bt_data sd[] = {
	BT_DATA(BT_DATA_MANUFACTURER_DATA, led_scan_resp,sizeof(led_scan_resp)),
};

struct __attribute__((packed)) image_header {
	uint16_t length;
	uint16_t data_type;
	uint8_t option;
};

int recovery_timeout = 0;
int shutdown_timeout = 0;
float global_brightness = 0.3f;
static const struct gpio_dt_spec wakeup_button = GPIO_DT_SPEC_GET(DT_ALIAS(wakeup), gpios);

#define GAMMA_VAL 2.0
// #define DEVICE_TYPE 0x85 // 64x20
#define DEVICE_TYPE 0x82 // 32x16

void parseCommandPacket(const void *buf, uint16_t len);
void imageCommand(const void *buf, uint16_t len);
void process_gif(const uint8_t* gif_data, size_t gif_size);
void process_png(const uint8_t* png_data, size_t png_size);
void live_draw(uint8_t pixel_index, struct led_rgb color);
struct led_rgb gamma_correction(struct led_rgb color);
struct led_rgb set_brightness(struct led_rgb color, float brightness);
void set_global_brightness(float brightness);
void clear_display();
void display_debug();
void display_warn();
void render();
void check_for_recovery_mode();
void check_power_off();
void playback_animation(struct pixel_animation *animation);
int save_pixels_to_file(const char *filename);

static ssize_t write_led(struct bt_conn *conn,
			 const struct bt_gatt_attr *attr,
			 const void *buf,
			 uint16_t len, uint16_t offset, uint8_t flags);

static ssize_t read_led(struct bt_conn *conn,
			 const struct bt_gatt_attr *attr,
			 void *buf,
			 uint16_t len, uint16_t offset);

static void lbslc_ccc_cfg_changed(const struct bt_gatt_attr *attr,
				  uint16_t value);

BT_GATT_SERVICE_DEFINE(led_svc,
BT_GATT_PRIMARY_SERVICE(BT_UUID_IPIXEL_SRV),
	BT_GATT_CHARACTERISTIC(BT_UUID_IPIXEL_WRITE,
			       BT_GATT_CHRC_WRITE_WITHOUT_RESP | BT_GATT_CHRC_WRITE,
			       BT_GATT_PERM_WRITE |
			       BT_GATT_PERM_PREPARE_WRITE,
			       read_led, write_led, NULL),
	BT_GATT_CUD("TR2310R003-21", BT_GATT_PERM_READ),
	BT_GATT_CHARACTERISTIC(BT_UUID_IPIXEL_NOTIFY,
			       BT_GATT_CHRC_NOTIFY,
			       BT_GATT_PERM_READ,
			       read_led, write_led, NULL),
	BT_GATT_CCC(lbslc_ccc_cfg_changed,
		    BT_GATT_PERM_READ | BT_GATT_PERM_WRITE),
);

// BT_GATT_SERVICE_DEFINE(led_svc_ae,
// BT_GATT_PRIMARY_SERVICE(BT_UUID_IPIXEL_SRV_AE),
// 	BT_GATT_CHARACTERISTIC(BT_UUID_IPIXEL_WRITE_AE,
// 			       BT_GATT_CHRC_WRITE_WITHOUT_RESP,
// 			       BT_GATT_PERM_WRITE |
// 			       BT_GATT_PERM_PREPARE_WRITE,
// 			       read_led, write_led, NULL),
// 	BT_GATT_CHARACTERISTIC(BT_UUID_IPIXEL_NOTIFY_AE,
// 			       BT_GATT_CHRC_NOTIFY,
// 			       BT_GATT_PERM_READ,
// 			       read_led, write_led, NULL),
// 	BT_GATT_CCC(lbslc_ccc_cfg_changed,
// 		    BT_GATT_PERM_READ | BT_GATT_PERM_WRITE),
// );


static void lbslc_ccc_cfg_changed(const struct bt_gatt_attr *attr,
				  uint16_t value)
{
	LOG_INF("cfg_change: %u", value);
	notify_enabled = (value == BT_GATT_CCC_NOTIFY);
	if(notify_enabled) {
		LOG_INF("Notifications enabled");
			uint8_t info_notify2[] = {0x00, 0x05, 0x80, 0x0f, 0x15, 0x01, 0x05};
			bt_gatt_notify(NULL, &led_svc.attrs[5], &info_notify2, sizeof(info_notify2));
			// bt_gatt_notify(NULL, &led_svc_ae.attrs[4], &info_notify2, sizeof(info_notify2));

			uint8_t info_notify[11] = {0x0b, 0x00, 0x01, 0x80, DEVICE_TYPE, 0x02, 0x2c, 0x00, 0x00, 0x01, 0x00};
			bt_gatt_notify(NULL, &led_svc.attrs[5], &info_notify, sizeof(info_notify));
			// bt_gatt_notify(NULL, &led_svc_ae.attrs[4], &info_notify, sizeof(info_notify));

		
	}
}


static ssize_t write_led(struct bt_conn *conn,
			 const struct bt_gatt_attr *attr,
			 const void *buf,
			 uint16_t len, uint16_t offset, uint8_t flags)
{
	// LOG_INF("LED attribute write, handle: %u, conn: %p", attr->handle, (void *)conn);

	LOG_INF("\nNew packet of length: %u", len);
	
	if(len < 250){
		LOG_HEXDUMP_INF(buf, len, "data:");
	}
	// LOG_INF("Offset: %u", offset);
	// LOG_INF("Flags: %u", flags);

	if(len >= 4){
		if(((uint8_t *)buf)[3] == 0x80) {
			LOG_INF("Command packet received");
			parseCommandPacket(buf, len);
		} else {
			LOG_INF("Data packet received");
			imageCommand(buf, len);
		}
	}else {
		LOG_ERR("Write led: Incorrect data length: %u", len);
		return BT_GATT_ERR(BT_ATT_ERR_INVALID_ATTRIBUTE_LEN);
	}


	return len;
}


void parseCommandPacket(const void *buf, uint16_t len)
{
	LOG_INF("Parsing command packet...");
	const uint8_t *data = (const uint8_t *)buf;
	uint8_t commandType = data[0];
	switch(commandType) {
		case 0x08:
			LOG_INF("Device Info Request received");
			uint8_t info_notify[11] = {0x0b, 0x00, 0x01, 0x80, DEVICE_TYPE, 0x02, 0x2c, 0x00, 0x00, 0x01, 0x00};
			bt_gatt_notify(NULL, &led_svc.attrs[5], &info_notify, sizeof(info_notify));
			break;
		case 0x07:
			LOG_INF("Image ack request received");
			unsigned char bytes[] = {0x5, 0x0, 0x8, 0x80, 0x1};
			bt_gatt_notify(NULL, &led_svc.attrs[5], &bytes, sizeof(bytes));
			unsigned char bytes2[] = {0x5, 0x0, 0x11, 0x0, 0x3};
			bt_gatt_notify(NULL, &led_svc.attrs[5], &bytes2, sizeof(bytes2));
			break;
		case 0x05:
			if(data[2] == 0x04) {
				LOG_INF("Brightness adjustment packet received: %f / %u", (double)(data[4] / 100.0f), data[4]);
				float brightness = data[4] / 100.0f;
				set_global_brightness(brightness);
			}
			break;
		case 0x04:
			if(data[2] == 0x03) {
				LOG_INF("Clear display command received");
				// clear display
				clear_display();
			}
			break;
		default:
			LOG_WRN("Unknown command type: %#02x", commandType);
			break;
	}
}

void imageCommand(const void *buf, uint16_t len)
{
	LOG_INF("Parsing image command packet...");
	uint8_t *data = (const uint8_t *)buf;
	
	if(len <= 10){
		uint8_t commandType = data[0];
		switch(commandType) {
		case 0x05:
			if(data[2] == 0x04 && data[3] == 0x01) {
				if(data[4] == 0x01){
					LOG_INF("Live draw start packet received");
					clear_display();
				} else if(data[4] == 0x00){
					LOG_INF("Live draw stop packet received");
					// respond with ack by sending packet back
					data[3] = 0x01;
					bt_gatt_notify(NULL, &led_svc.attrs[5], data, len);
					save_pixels_to_file("/lfs1/default.dat");
				}
			} else {
				LOG_WRN("Unknown Draw Command Packet received");
			}
			break;
		case 0x0a:
			LOG_INF("Live draw pixel data packet received");
			if(len > 10){
				LOG_ERR("Invalid live draw pixel data packet length: %u", len);
				break;
			}
			if(data[9] != 0x00) {
				break;
			}
			uint8_t pixel_index = data[8];
			struct led_rgb color;
			color.r = data[5];
			color.g = data[6];
			color.b = data[7];
			live_draw(pixel_index, color);
			break;
		default:
			LOG_WRN("Unknown image command type: %#02x", commandType);
			break;
		}
	}else{
		LOG_INF("Bitmap data packet received, length: %u", len);
		struct image_header img_header;
		memcpy(&img_header, &data[0], sizeof(img_header));
		LOG_INF("Image length: %u, data type: %#04x, option: %#02x", img_header.length, img_header.data_type, img_header.option);

		// GIF
		if(img_header.data_type == 0x03 && data[15] == 0x47 && data[16] == 0x49 && data[17] == 0x46){
			LOG_INF("GIF header detected");
			process_gif(&data[15], len - 15);
			// acknowledge receipt
			unsigned char bytes[] = {0x5, 0x0, 0x8, 0x80, 0x1};
			bt_gatt_notify(NULL, &led_svc.attrs[5], &bytes, sizeof(bytes));
			unsigned char bytes2[] = {0x5, 0x0, 0x3, 0x0, 0x3};
			bt_gatt_notify(NULL, &led_svc.attrs[5], &bytes2, sizeof(bytes2));
			playAnimation = true;
		}
		
		// PNG
		if(data[15] == 0x89 && data[16] == 0x50 && data[17] == 0x4e && data[18] == 0x47){
			LOG_INF("PNG header detected");
			process_png(&data[15], len - 15);
			// acknowledge receipt
			unsigned char bytes[] = {0x5, 0x0, 0x8, 0x80, 0x1};
			bt_gatt_notify(NULL, &led_svc.attrs[5], &bytes, sizeof(bytes));
			unsigned char bytes2[] = {0x5, 0x0, 0x3, 0x0, 0x3};
			bt_gatt_notify(NULL, &led_svc.attrs[5], &bytes2, sizeof(bytes2));
		}
	}
	
}


void live_draw(uint8_t pixel_index, struct led_rgb color)
{

	if(pixel_index < STRIP_NUM_PIXELS){
		pixels_raw[pixel_index] = color;
		render();
	} else {
		LOG_ERR("live_draw: Pixel index out of bounds: %u", pixel_index);
	}
}

void clear_display()
{
	LOG_INF("Clearing display");
	memset(&pixels_raw, 0x00, sizeof(pixels_raw));
	render();
}

struct led_rgb gamma_correction(struct led_rgb color) {
	color.r = (uint8_t)(pow(color.r / 255.0, GAMMA_VAL) * 255);
	color.g = (uint8_t)(pow(color.g / 255.0, GAMMA_VAL) * 255);
	color.b = (uint8_t)(pow(color.b / 255.0, GAMMA_VAL) * 255);
	return color;
}

struct led_rgb set_brightness(struct led_rgb color, float brightness) {
	color.r = (uint8_t)(color.r * brightness);
	color.g = (uint8_t)(color.g * brightness);
	color.b = (uint8_t)(color.b * brightness);
	return color;
}

void render(){
	// check if if all black and turn off power if so
	for(int i = 0; i < STRIP_NUM_PIXELS; i++) {
		if(pixels_raw[i].r != 0 || pixels_raw[i].g != 0 || pixels_raw[i].b != 0) {
			goto draw;
		}
	}
	LOG_INF("All pixels black, turning off power to LED strip");
	regulator_disable(led_en);
	return;

	draw:
	if(!regulator_is_enabled(led_en)) {
		regulator_enable(led_en);
		k_sleep(K_USEC(500));
	}
	for(int i = 0; i < STRIP_NUM_PIXELS; i++) {
		pixels[i] = set_brightness(pixels_raw[i], global_brightness);
		pixels[i] = gamma_correction(pixels[i]);
	}
	int rc = led_strip_update_rgb(strip, pixels, STRIP_NUM_PIXELS);
	if (rc) {
		LOG_ERR("couldn't update strip: %d", rc);
	}
}

void set_global_brightness(float brightness) {
	global_brightness = brightness;
	render();
}

void process_png(const uint8_t* png_data, size_t png_size) {
	LOG_INF("Decoding PNG");

}

void process_gif(const uint8_t* gif_data, size_t gif_size) {
	LOG_INF("Decoding GIF");
    GIF_Context ctx;
    int result = gif_init(&ctx, gif_data, gif_size, 
                         scratch_buffer, sizeof(scratch_buffer));
    
    if(result != GIF_SUCCESS) {
        LOG_ERR("Error: %s\n", gif_get_error_string(result));
        return;
    }

    int width, height;
    gif_get_info(&ctx, &width, &height);
	LOG_INF("GIF dimensions: %dx%d", width, height);
    
    uint8_t* frame_buffer = malloc(width * height * 3);
	if(frame_buffer == NULL) {
		LOG_ERR("Failed to allocate GIF frame buffer\n");
		gif_close(&ctx);
		return;
	}
    int delay_ms;
    int frame_result;
    
    while((frame_result = gif_next_frame(&ctx, frame_buffer, &delay_ms)) > 0) {
        // Process frame
        // delay_ms contains frame duration
        LOG_INF("Frame decoded, delay: %d ms", delay_ms);
		LOG_HEXDUMP_INF(frame_buffer, 30 * 3, "Decoded GIF frame data:");
		// save frame to current_animation
		struct pixel_animation_frame frame;
		frame.duration_ms = delay_ms;
		memcpy(frame.pixels, frame_buffer, sizeof(frame.pixels));
		current_animation.frames = realloc(current_animation.frames, sizeof(struct pixel_animation_frame) * (current_animation.num_frames + 1));
		memcpy(&current_animation.frames[current_animation.num_frames], &frame, sizeof(struct pixel_animation_frame));
		current_animation.num_frames++;
    }
    
    if(frame_result < 0) {
        LOG_ERR("Decoding error: %s\n", gif_get_error_string(frame_result));
    }
    
    gif_close(&ctx);
    free(frame_buffer);
}

void playback_animation(struct pixel_animation *animation) {
	for(int i = 0; i < animation->num_frames; i++) {
		memcpy(pixels_raw, animation->frames[i].pixels, sizeof(pixels_raw));
		render();
		k_sleep(K_MSEC(animation->frames[i].duration_ms));
	}
}

static ssize_t read_led(struct bt_conn *conn,
			  const struct bt_gatt_attr *attr,
			  void *buf,
			  uint16_t len,
			  uint16_t offset)
{
	const char *value = attr->user_data;

	LOG_INF("Attribute read, handle: %u, conn: %p", attr->handle,
		(void *)conn);

	// if (lbs_cb.button_cb) {
	// 	button_state = lbs_cb.button_cb();
	// 	return bt_gatt_attr_read(conn, attr, buf, len, offset, value,
	// 				 sizeof(*value));
	// }

	return 0;
}



static void adv_work_handler(struct k_work *work)
{
	int err = bt_le_adv_start(BT_LE_ADV_CONN_FAST_2, ad, ARRAY_SIZE(ad), sd, ARRAY_SIZE(sd));

	if (err) {
		LOG_INF("Advertising failed to start (err %d)\n", err);
		return;
	}

	LOG_INF("Advertising successfully started\n");
}

static void advertising_start(void)
{
	k_work_submit(&adv_work);
}

static void connected(struct bt_conn *conn, uint8_t err)
{
	if (err) {
		LOG_INF("Connection failed, err 0x%02x %s\n", err, bt_hci_err_to_str(err));
		return;
	}
	LOG_INF("Connected\n");
	dk_set_led_on(CON_STATUS_LED);
}

static void disconnected(struct bt_conn *conn, uint8_t reason)
{
	LOG_INF("Disconnected, reason 0x%02x %s\n", reason, bt_hci_err_to_str(reason));

	dk_set_led_off(CON_STATUS_LED);
}

static void recycled_cb(void)
{
	LOG_INF("Connection object available from previous conn. Disconnect is complete!\n");
	advertising_start();
}


BT_CONN_CB_DEFINE(conn_callbacks) = {
	.connected        = connected,
	.disconnected     = disconnected,
	.recycled         = recycled_cb,
#ifdef CONFIG_BT_LBS_SECURITY_ENABLED
	.security_changed = security_changed,
#endif
};


static void input_event_callback(struct input_event *evt, void *user_data)
{
	switch(evt->code) {
		case INPUT_KEY_0:
			LOG_INF("Button 0 state: %s", evt->value ? "pressed" : "released");
			button0 = evt->value;
			break;
		case INPUT_KEY_1:
			LOG_INF("Button 1 state: %s", evt->value ? "pressed" : "released");
			button1 = evt->value;
			break;
		case INPUT_KEY_2:
			LOG_INF("Button 2 state: %s", evt->value ? "pressed" : "released");
			button2 = evt->value;
			break;
		case INPUT_KEY_3:
			LOG_INF("Button 3 state: %s", evt->value ? "pressed" : "released");
			button3 = evt->value;
			break;
		default:
			LOG_WRN("Unknown button event code: %u", evt->code);
			break;
	}
	
	if (evt->sync) {
		LOG_INF("Input event sync");
		k_sem_give(&sync);
	}
}

INPUT_CALLBACK_DEFINE(NULL, input_event_callback, NULL);


void display_debug()
{
	// all white
	for(int i = 0; i < STRIP_NUM_PIXELS; i++) {
		pixels_raw[i] = (struct led_rgb){.r = 255, .g = 255, .b = 255};
	}
	render();
}
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
int main(void)
{
	int blink_status = 0;
	int err;
	size_t color = 0;
	int rc;
	// NRF_POWER->GPREGRET = 0x57;
	// sys_reboot(0x57);
	regulator_enable(led_en);
	LOG_INF("build time: " __DATE__ " " __TIME__);

	k_sem_init(&sync, 0, 1);

	rc = STATS_INIT_AND_REG(smp_svr_stats, STATS_SIZE_32, "smp_svr_stats");
	if (rc < 0) {
		LOG_ERR("Error initializing stats system [%d]", rc);
	}

	rc = fs_mount(&littlefs_mnt);
	if (rc < 0) {
		LOG_ERR("Error mounting littlefs [%d]", rc);
	}

	if (!device_is_ready(strip)) {
		LOG_ERR("LED strip device %s is not ready", strip->name);
		return 0;
	}

	err = dk_leds_init();
	if (err) {
		LOG_INF("LEDs init failed (err %d)\n", err);
		return 0;
	}


	err = bt_enable(NULL);
	if (err) {
		LOG_INF("Bluetooth init failed (err %d)\n", err);
		return 0;
	}

	LOG_INF("Bluetooth initialized\n");

	if (IS_ENABLED(CONFIG_SETTINGS)) {
		settings_load();
	}
	
	
	char addr_s[BT_ADDR_LE_STR_LEN];
	bt_addr_le_t addr = {0};
	size_t count = 1;
	bt_id_get(&addr, &count);
	bt_addr_le_to_str(&addr, addr_s, sizeof(addr_s));
	// null terminated device name
	char updated_name[sizeof(device_name)+1];
	updated_name[sizeof(device_name)] = '\0';

	LOG_INF("Bluetooth Address: %s", addr_s);
	memcpy(&device_name[sizeof(device_name) - 8], &addr_s[6], 2);
	memcpy(&device_name[sizeof(device_name) - 6], &addr_s[9], 2);
	memcpy(&device_name[sizeof(device_name) - 4], &addr_s[12], 2);
	memcpy(&device_name[sizeof(device_name) - 2], &addr_s[15], 2);
	LOG_INF("Device name: %s.", device_name);
	bt_le_adv_update_data(ad, ARRAY_SIZE(ad), sd, ARRAY_SIZE(sd));
	memcpy(&updated_name, &device_name, sizeof(device_name));
	bt_set_name((const char *)updated_name);


	STATS_SET(smp_svr_stats, version_major, FW_VERSION_MAJOR);
	STATS_SET(smp_svr_stats, version_minor, FW_VERSION_MINOR);


	k_work_init(&adv_work, adv_work_handler);
	advertising_start();
	clear_display();
	load_pixels_from_file("/lfs1/default.dat");
	
	if (boot_is_img_confirmed() == 0) {
        LOG_WRN("Boot image not confirmed. Confirming now.");
        boot_write_img_confirmed();
    }
	
	for (;;) {
		// dk_set_led(RUN_STATUS_LED, (++blink_status) % 2);
		
		// STATS_INC(smp_svr_stats, ticks);
		// k_sleep(K_MSEC(RUN_LED_BLINK_INTERVAL));
		if(playAnimation) {
			playback_animation(&current_animation);
		}
		k_sem_take(&sync, K_MSEC(1));
		check_for_recovery_mode();
		check_power_off();
		
	}
}

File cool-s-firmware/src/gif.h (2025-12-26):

/**
 * @file gif.h
 * @brief Header-only library for decoding GIF images.
 *
 * This library provides a minimalistic, header-only, and platform-independent API
 * for decoding animated GIF files. It combines LZW decoding optimizations
 * (Turbo LZW) with a compact design, avoiding dynamic memory allocations.
 *
 * @author Ferki
 * @date 16.07.2025
 */

#ifndef GIF_H
#define GIF_H

#include <stdint.h>
#include <string.h> // For memcpy, memset
#include <stddef.h> // For size_t

#ifdef __cplusplus
extern "C" {
#endif

// --- Constants and Configuration ---

/**
 * @brief Define GIF_IMPLEMENTATION in one C/C++ file to include the implementation.
 *
 * Example:
 * @code
 * // my_app.c
 * #define GIF_IMPLEMENTATION
 * #include "gif.h"
 * @endcode
 */
// #define GIF_IMPLEMENTATION

/**
 * @brief Define GIF_TEST to enable test functions.
 *
 * Example:
 * @code
 * // my_app.c
 * #define GIF_IMPLEMENTATION
 * #define GIF_TEST
 * #include "gif.h"
 * 
 * int main() {
 *     return gif_run_tests();
 * }
 * @endcode
 */
// #define GIF_TEST

/**
 * @brief Define GIF_MODE_TURBO for faster decoding with a larger scratch buffer.
 *
 * If not defined, a more memory-efficient (but potentially slower) mode is used.
 */
// #define GIF_MODE_TURBO

/**
 * @brief Maximum supported GIF canvas width.
 * Can be overridden by defining GIF_MAX_WIDTH before including this header.
 */
#ifndef GIF_MAX_WIDTH
#define GIF_MAX_WIDTH 480
#endif

/**
 * @brief Maximum number of colors in a GIF palette.
 * Can be overridden by defining GIF_MAX_COLORS before including this header.
 */
#ifndef GIF_MAX_COLORS
#define GIF_MAX_COLORS 256
#endif

/**
 * @brief Maximum LZW code size.
 * Can be overridden by defining GIF_MAX_CODE_SIZE before including this header.
 */
#ifndef GIF_MAX_CODE_SIZE
#define GIF_MAX_CODE_SIZE 12
#endif

/** @brief Size of an LZW data block fragment. */
#define GIF_LZW_CHUNK_SIZE 255
/** @brief Base LZW buffer size for codes. */
#define GIF_LZW_BASE_BUF_SIZE (6 * GIF_LZW_CHUNK_SIZE)
/** @brief Number of entries in the LZW table. */
#define GIF_LZW_TABLE_ENTRIES (1 << GIF_MAX_CODE_SIZE) // 4096 entries

/**
 * @brief Defines the minimum required size for the internal scratch buffer.
 *
 * The user must provide a buffer of at least this size to gif_init().
 */
#ifdef GIF_MODE_TURBO
    /** @brief Size of the LZW dictionary symbols for Turbo mode. */
    #define GIF_SCRATCH_LZW_DICT_SYMBOLS_SIZE (GIF_LZW_TABLE_ENTRIES * sizeof(uint32_t))
    /** @brief Size of the LZW dictionary lengths for Turbo mode. */
    #define GIF_SCRATCH_LZW_DICT_LENGTHS_SIZE (GIF_LZW_TABLE_ENTRIES * sizeof(uint16_t))
    /** @brief Size of the LZW pixels suffix buffer for Turbo mode. */
    #define GIF_SCRATCH_LZW_PIXELS_SUFFIX_SIZE (GIF_LZW_TABLE_ENTRIES * sizeof(uint8_t))
    /** @brief Main LZW buffer size for Turbo mode. */
    #define GIF_SCRATCH_LZW_MAIN_BUF_SIZE (GIF_LZW_BASE_BUF_SIZE + (2 * GIF_LZW_TABLE_ENTRIES) + (GIF_LZW_TABLE_ENTRIES * 2) + GIF_MAX_WIDTH)
    /** @brief Total required scratch buffer size for Turbo mode. */
    #define GIF_SCRATCH_BUFFER_REQUIRED_SIZE (GIF_SCRATCH_LZW_MAIN_BUF_SIZE + GIF_SCRATCH_LZW_DICT_SYMBOLS_SIZE + GIF_SCRATCH_LZW_DICT_LENGTHS_SIZE + GIF_SCRATCH_LZW_PIXELS_SUFFIX_SIZE + GIF_MAX_WIDTH)
#else
    /** @brief Size of the LZW table for Safe mode. */
    #define GIF_SCRATCH_LZW_TABLE_SIZE (GIF_LZW_TABLE_ENTRIES * sizeof(uint16_t))
    /** @brief Size of the LZW pixels buffer for Safe mode. */
    #define GIF_SCRATCH_LZW_PIXELS_SIZE (GIF_LZW_TABLE_ENTRIES * 2 * sizeof(uint8_t))
    /** @brief Main LZW buffer size for Safe mode. */
    #define GIF_SCRATCH_LZW_MAIN_BUF_SIZE GIF_LZW_BASE_BUF_SIZE
    /** @brief Total required scratch buffer size for Safe mode. */
    #define GIF_SCRATCH_BUFFER_REQUIRED_SIZE (GIF_SCRATCH_LZW_MAIN_BUF_SIZE + GIF_SCRATCH_LZW_TABLE_SIZE + GIF_SCRATCH_LZW_PIXELS_SIZE + GIF_MAX_WIDTH)
#endif

// --- Error Codes ---
/**
 * @brief Enumeration of error codes that can be returned by the library.
 */
enum {
   /** @brief Operation completed successfully. */
   GIF_SUCCESS = 0,
   /** @brief Error during LZW data decoding. */
   GIF_ERROR_DECODE,
   /** @brief Invalid parameter passed (e.g., NULL pointer). */
   GIF_ERROR_INVALID_PARAM,
   /** @brief The GIF file has an invalid format or is corrupted. */
   GIF_ERROR_BAD_FILE,
   /** @brief Unexpected end of file encountered while reading data. */
   GIF_ERROR_EARLY_EOF,
   /** @brief No next frame found to decode. */
   GIF_ERROR_NO_FRAME,
   /** @brief The user-provided buffer is too small. */
   GIF_ERROR_BUFFER_TOO_SMALL,
   /** @brief Invalid frame dimensions (e.g., zero width/height, or extends beyond canvas). */
   GIF_ERROR_INVALID_FRAME_DIMENSIONS,
   /** @brief Unsupported color depth (e.g., palette size exceeds GIF_MAX_COLORS). */
   GIF_ERROR_UNSUPPORTED_COLOR_DEPTH,
   /** @brief Internal buffer overflow detected. */
   GIF_ERROR_BUFFER_OVERFLOW,
   /** @brief Invalid LZW code encountered during decoding. */
   GIF_ERROR_INVALID_LZW_CODE
};

/**
 * @brief Type definition for an error callback function.
 *
 * The user can provide their own function for logging or handling errors.
 * @param error_code The error code from the enumeration.
 * @param message A descriptive message about the error.
 */
typedef void (*GIF_ErrorCallback)(int error_code, const char* message);
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

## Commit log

2025-12-26 add initial release
    [Cool-S-Budget v6_bom.csv, Cool-S-Budget.brd, Cool-S-Budget.sch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]
2025-12-27 add minimal docs
    [Back-Cover-Cool-S.step]
2025-12-27 add power instructions
2026-01-01 fix iPhone discovery for iPixel app
    [main.c]
2026-01-01 fix iOS pixel drawing
    [main.c]

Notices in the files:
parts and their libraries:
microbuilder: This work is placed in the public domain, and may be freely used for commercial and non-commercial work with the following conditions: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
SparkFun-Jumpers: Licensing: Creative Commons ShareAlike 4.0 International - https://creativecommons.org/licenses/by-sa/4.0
